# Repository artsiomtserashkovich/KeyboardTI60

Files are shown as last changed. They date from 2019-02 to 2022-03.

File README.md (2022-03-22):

TI60
===

A common 60% PCB with RGB Backlight.

## TI60 Hardware Information

    MCU: Atmega32u4
    Led Driver: IS31FL3731
    Leds: WS2812
    
    Led Pin: D2
    Led Drive Pins: D0 D1 (I2C) 

    /* Column pin configuration
    * col: 1   2   3   4   5   6   7   8   9   10   11  12  13  14  15
    * pin: F1  B0  F5  B1  F6  B2  F7  B3  C7  B7   C6  D3  B6  D5  F0
    */
     
    /* Row pin configuration
    * row: 1   2   3   4   5
    * pin: D4  D6  D7  B4  B5
    */

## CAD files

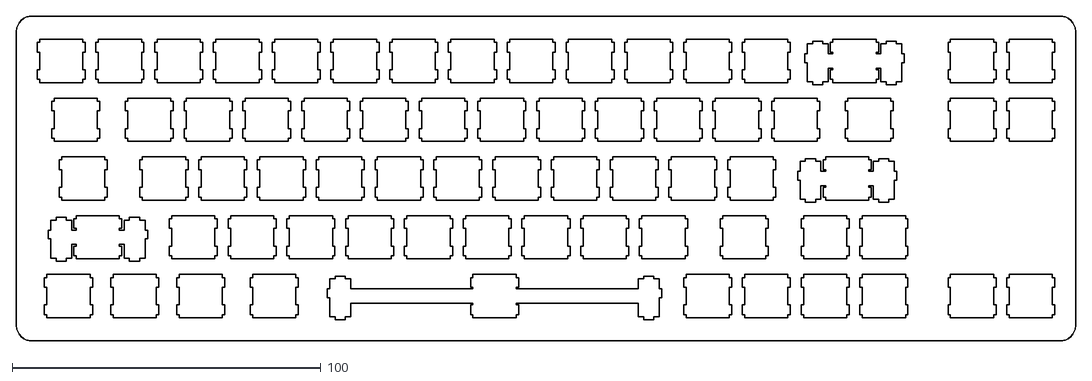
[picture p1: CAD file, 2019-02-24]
Hardware/plate/9ef09e29135e2a51376023435b0bfdb50b335f7b_switch.dxf
343.4 x 105.3

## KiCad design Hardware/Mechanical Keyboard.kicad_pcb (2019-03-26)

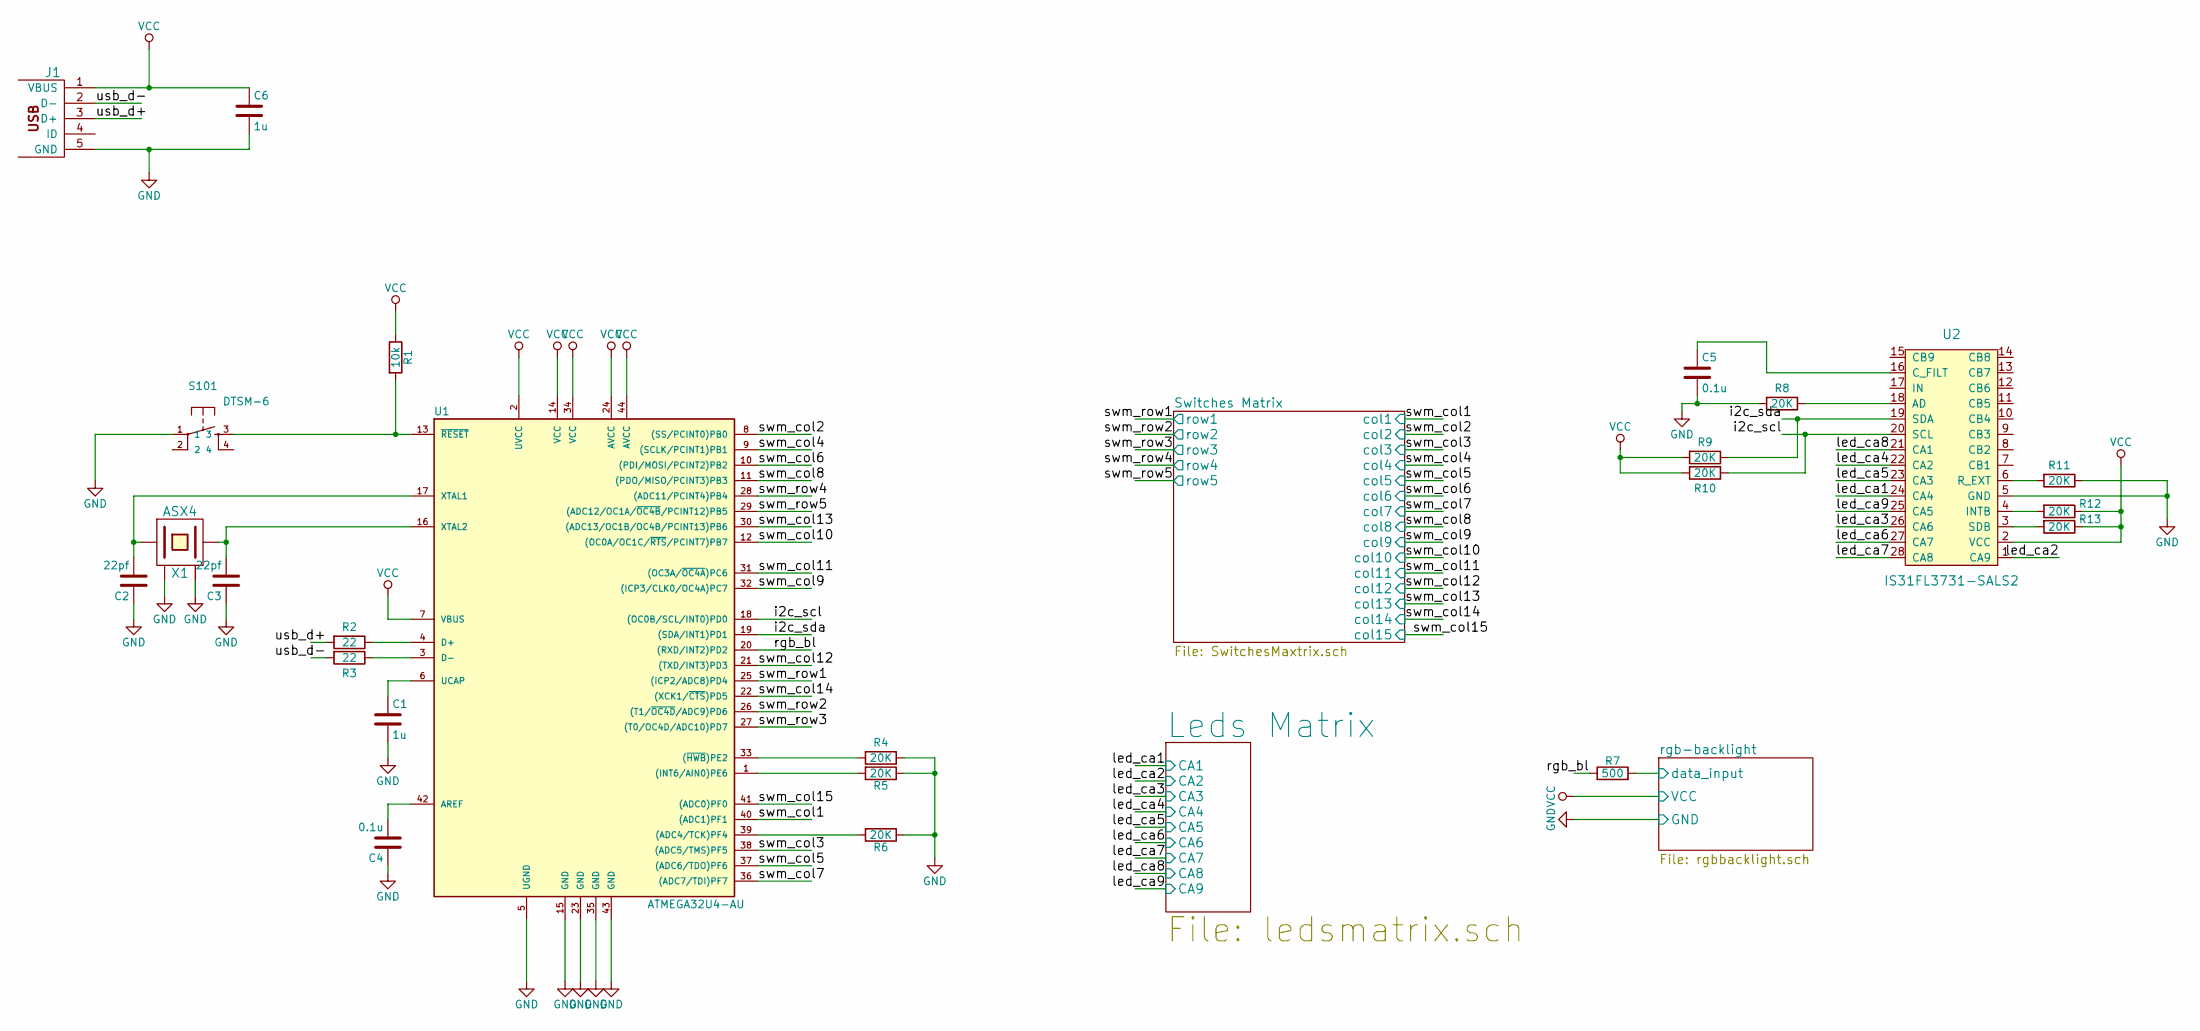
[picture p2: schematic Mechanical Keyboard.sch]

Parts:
C1, C6: 1u; C_0805_HandSoldering
C2, C3: 22pf; C_0805_HandSoldering
C4, C5: 0.1u; C_0805_HandSoldering
J1: USBMINI_B05; 67503
R1: 10k; R_0805_HandSoldering
R2, R3: 22; R_0805_HandSoldering
R4, R5, R6, R8, R9, R10, R11, R12, R13: 20K; R_0805_HandSoldering
R7: 500; R_0805_HandSoldering
S101: DTSM-6; KSEM31GLFS
U1: ATMEGA32U4-AU; TQFP-44_10x10mm_Pitch0.8mm
U2: IS31FL3731-SALS2; QFN-28-1EP_4x4mm_Pitch0.4mm
X1: ASX4; 4-SMD

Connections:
/i2c_scl: R10.1, U1.18 ((OC0B/SCL/INT0)PD0), U2.20 (SCL)
/i2c_sda: R9.1, U1.19 ((SDA/INT1)PD1), U2.19 (SDA)
/led_ca1: U2.24 (CA4); also elsewhere on the board
/led_ca2: U2.1 (CA9); also elsewhere on the board
/led_ca3: U2.26 (CA6); also elsewhere on the board
/led_ca4: U2.22 (CA2); also elsewhere on the board
/led_ca5: U2.23 (CA3); also elsewhere on the board
/led_ca6: U2.27 (CA7); also elsewhere on the board
/led_ca7: U2.28 (CA8); also elsewhere on the board
/led_ca8: U2.21 (CA1); also elsewhere on the board
/led_ca9: U2.25 (CA5); also elsewhere on the board
/rgb-backlight/data_input: R7.2; also elsewhere on the board
/rgb_bl: R7.1, U1.20 ((RXD/INT2)PD2)
/swm_col1: U1.40 ((ADC1)PF1); also elsewhere on the board
/swm_col2: U1.8 ((SS/PCINT0)PB0); also elsewhere on the board
/swm_col3: U1.38 ((ADC5/TMS)PF5); also elsewhere on the board
/swm_col4: U1.9 ((SCLK/PCINT1)PB1); also elsewhere on the board
/swm_col5: U1.37 ((ADC6/TDO)PF6); also elsewhere on the board
/swm_col6: U1.10 ((PDI/MOSI/PCINT2)PB2); also elsewhere on the board
/swm_col7: U1.36 ((ADC7/TDI)PF7); also elsewhere on the board
/swm_col8: U1.11 ((PDO/MISO/PCINT3)PB3); also elsewhere on the board
/swm_col9: U1.32 ((ICP3/CLK0/OC4A)PC7); also elsewhere on the board
/swm_col10: U1.12 ((OC0A/OC1C/~RTS~/PCINT7)PB7); also elsewhere on the board
/swm_col11: U1.31 ((OC3A/~OC4A~)PC6); also elsewhere on the board
/swm_col12: U1.21 ((TXD/INT3)PD3); also elsewhere on the board
/swm_col13: U1.30 ((ADC13/OC1B/OC4B/PCINT13)PB6); also elsewhere on the board
/swm_col14: U1.22 ((XCK1/~CTS~)PD5); also elsewhere on the board
/swm_col15: U1.41 ((ADC0)PF0); also elsewhere on the board
/swm_row1: U1.25 ((ICP2/ADC8)PD4); also elsewhere on the board
/swm_row2: U1.26 ((T1/~OC4D~/ADC9)PD6); also elsewhere on the board
/swm_row3: U1.27 ((T0/OC4D/ADC10)PD7); also elsewhere on the board
/swm_row4: U1.28 ((ADC11/PCINT4)PB4); also elsewhere on the board
/swm_row5: U1.29 ((ADC12/OC1A/~OC4B~/PCINT12)PB5); also elsewhere on the board
/usb_d+: J1.3 (D+), R2.2
/usb_d-: J1.2 (D-), R3.2
GND: C1.2, C2.1, C3.1, C4.1, C5.2, C6.2, J1.5 (GND), R4.1, R5.1, R6.1, R8.2, R11.1, S101.1, U1.5 (UGND), U1.15 (GND), U1.23 (GND), U1.35 (GND), U1.43 (GND), U2.5 (GND), X1.2 (GND), X1.4 (GND); also elsewhere on the board
unnamed: C1.1, U1.6 (UCAP)
unnamed: C2.2, U1.17 (XTAL1), X1.1
unnamed: C3.2, U1.16 (XTAL2), X1.3 (2)
unnamed: C4.2, U1.42 (AREF)
unnamed: C5.1, U2.16 (C_FILT)
unnamed: R1.2, S101.3, U1.13 (~RESET~)
unnamed: R2.1, U1.4 (D+)
unnamed: R3.1, U1.3 (D-)
unnamed: R4.2, U1.33 ((~HWB~)PE2)
unnamed: R5.2, U1.1 ((INT6/AIN0)PE6)
unnamed: R6.2, U1.39 ((ADC4/TCK)PF4)
unnamed: R8.1, U2.18 (AD)
unnamed: R11.2, U2.6 (R_EXT)
unnamed: R12.2, U2.4 (INTB)
unnamed: R13.2, U2.3 (SDB)
VCC: C6.1, J1.1 (VBUS), R1.1, R9.2, R10.2, R12.1, R13.1, U1.2 (UVCC), U1.7 (VBUS), U1.14 (VCC), U1.24 (AVCC), U1.34 (VCC), U1.44 (AVCC), U2.2 (VCC); also elsewhere on the board

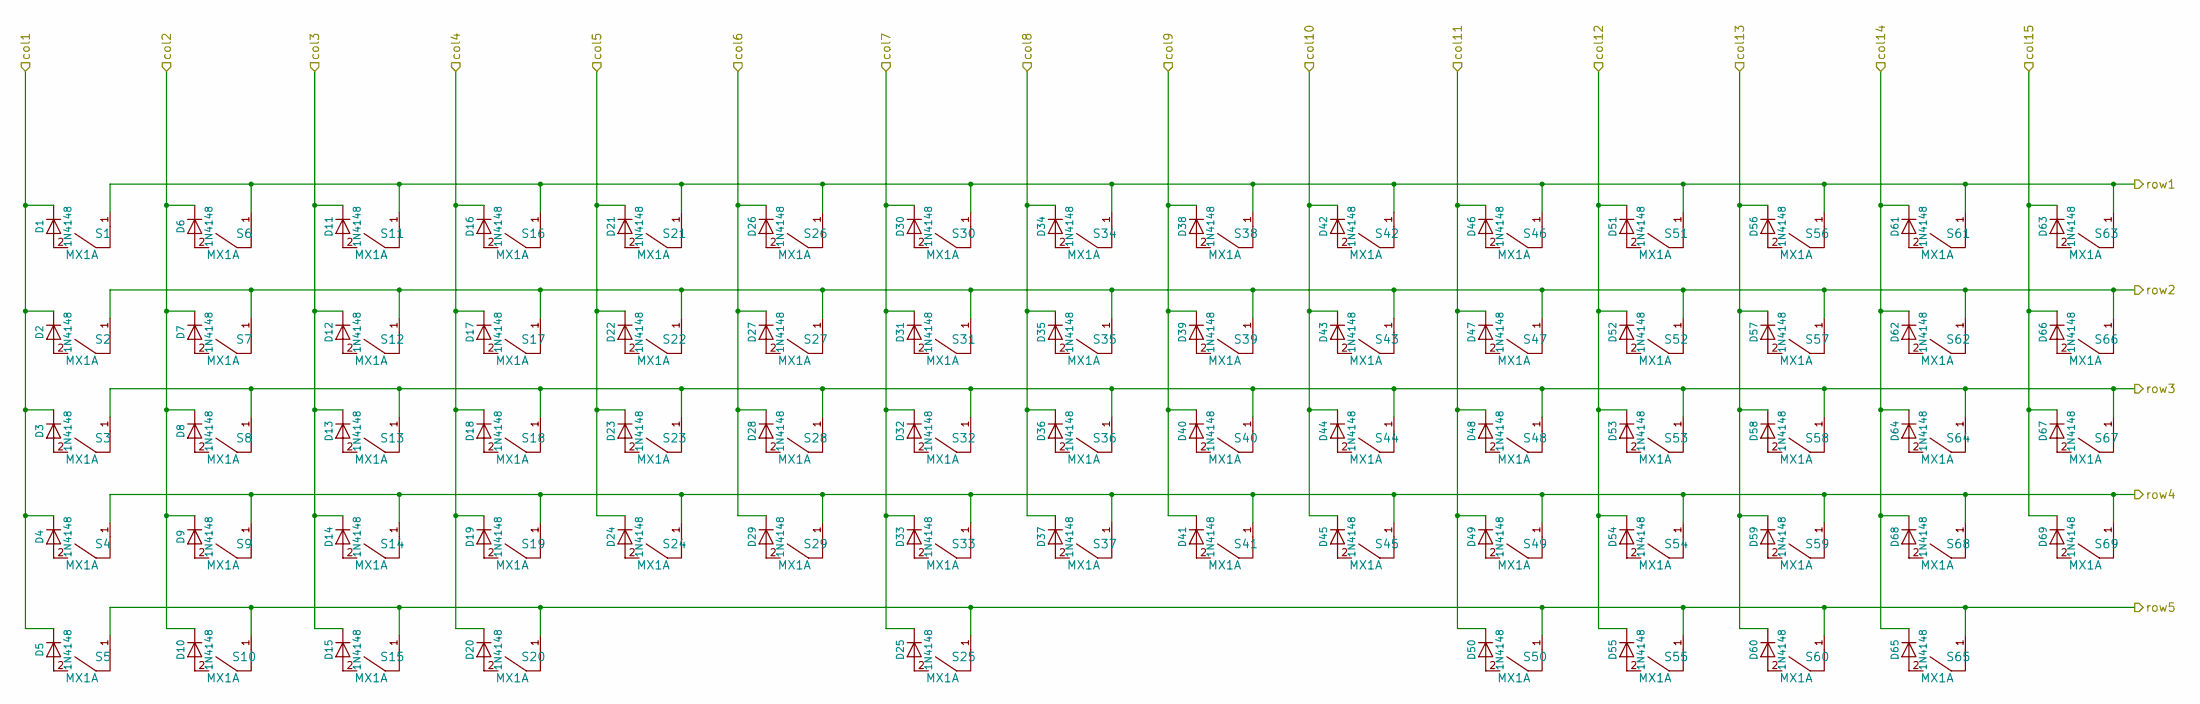
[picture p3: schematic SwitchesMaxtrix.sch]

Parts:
D1, D2, D3, D4, D5, D6, D7, D8, D9, D10, D11, D12, D13, D14, D15, D16, D17, D18, D19, D20, D21, D22, D23, D24, D25, D26, D27, D28, D29, D30, D31, D32, D33, D34, D35, D36, D37, D38, D39, D40, D41, D42, D43, D44, D45, D46, D47, D48, D49, D50, D51, D52, D53, D54, D55, D56, D57, D58, D59, D60, D61, D62, D63, D64, D65, D66, D67, D68, D69: 1N4148; D_SOD-123
S1, S2, S3, S4, S5, S6, S7, S8, S9, S10, S11, S12, S13, S14, S15, S16, S17, S18, S19, S20, S21, S22, S23, S24, S25, S26, S27, S28, S29, S30, S31, S32, S33, S34, S35, S36, S37, S38, S39, S40, S41, S42, S43, S44, S45, S46, S47, S48, S49, S50, S51, S52, S53, S54, S55, S56, S57, S58, S59, S60, S61, S62, S63, S64, S65, S66, S67, S68, S69: MX1A

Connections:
/swm_col1: D1.1 (K), D2.1 (K), D3.1 (K), D4.1 (K), D5.1 (K); also elsewhere on the board
/swm_col2: D6.1 (K), D7.1 (K), D8.1 (K), D9.1 (K), D10.1 (K); also elsewhere on the board
/swm_col3: D11.1 (K), D12.1 (K), D13.1 (K), D14.1 (K), D15.1 (K); also elsewhere on the board
/swm_col4: D16.1 (K), D17.1 (K), D18.1 (K), D19.1 (K), D20.1 (K); also elsewhere on the board
/swm_col5: D21.1 (K), D22.1 (K), D23.1 (K), D24.1 (K); also elsewhere on the board
/swm_col6: D26.1 (K), D27.1 (K), D28.1 (K), D29.1 (K); also elsewhere on the board
/swm_col7: D25.1 (K), D30.1 (K), D31.1 (K), D32.1 (K), D33.1 (K); also elsewhere on the board
/swm_col8: D34.1 (K), D35.1 (K), D36.1 (K), D37.1 (K); also elsewhere on the board
/swm_col9: D38.1 (K), D39.1 (K), D40.1 (K), D41.1 (K); also elsewhere on the board
/swm_col10: D42.1 (K), D43.1 (K), D44.1 (K), D45.1 (K); also elsewhere on the board
/swm_col11: D46.1 (K), D47.1 (K), D48.1 (K), D49.1 (K), D50.1 (K); also elsewhere on the board
/swm_col12: D51.1 (K), D52.1 (K), D53.1 (K), D54.1 (K), D55.1 (K); also elsewhere on the board
/swm_col13: D56.1 (K), D57.1 (K), D58.1 (K), D59.1 (K), D60.1 (K); also elsewhere on the board
/swm_col14: D61.1 (K), D62.1 (K), D64.1 (K), D65.1 (K), D68.1 (K); also elsewhere on the board
/swm_col15: D63.1 (K), D66.1 (K), D67.1 (K), D69.1 (K); also elsewhere on the board
/swm_row1: S1.1, S6.1, S11.1, S16.1, S21.1, S26.1, S30.1, S34.1, S38.1, S42.1, S46.1, S51.1, S56.1, S61.1, S63.1; also elsewhere on the board
/swm_row2: S2.1, S7.1, S12.1, S17.1, S22.1, S27.1, S31.1, S35.1, S39.1, S43.1, S47.1, S52.1, S57.1, S62.1, S66.1; also elsewhere on the board
/swm_row3: S3.1, S8.1, S13.1, S18.1, S23.1, S28.1, S32.1, S36.1, S40.1, S44.1, S48.1, S53.1, S58.1, S64.1, S67.1; also elsewhere on the board
/swm_row4: S4.1, S9.1, S14.1, S19.1, S24.1, S29.1, S33.1, S37.1, S41.1, S45.1, S49.1, S54.1, S59.1, S68.1, S69.1; also elsewhere on the board
/swm_row5: S5.1, S10.1, S15.1, S20.1, S25.1, S50.1, S55.1, S60.1, S65.1; also elsewhere on the board
unnamed: D1.2 (A), S1.2
unnamed: D2.2 (A), S2.2
unnamed: D3.2 (A), S3.2
unnamed: D4.2 (A), S4.2
unnamed: D5.2 (A), S5.2
unnamed: D6.2 (A), S6.2
unnamed: D7.2 (A), S7.2
unnamed: D8.2 (A), S8.2
unnamed: D9.2 (A), S9.2
unnamed: D10.2 (A), S10.2
unnamed: D11.2 (A), S11.2
unnamed: D12.2 (A), S12.2
unnamed: D13.2 (A), S13.2
unnamed: D14.2 (A), S14.2
unnamed: D15.2 (A), S15.2
unnamed: D16.2 (A), S16.2
unnamed: D17.2 (A), S17.2
unnamed: D18.2 (A), S18.2
unnamed: D19.2 (A), S19.2
unnamed: D20.2 (A), S20.2
unnamed: D21.2 (A), S21.2
unnamed: D22.2 (A), S22.2
unnamed: D23.2 (A), S23.2
unnamed: D24.2 (A), S24.2
unnamed: D25.2 (A), S25.2
unnamed: D26.2 (A), S26.2
unnamed: D27.2 (A), S27.2
unnamed: D28.2 (A), S28.2
unnamed: D29.2 (A), S29.2
unnamed: D30.2 (A), S30.2
unnamed: D31.2 (A), S31.2
unnamed: D32.2 (A), S32.2
unnamed: D33.2 (A), S33.2
unnamed: D34.2 (A), S34.2
unnamed: D35.2 (A), S35.2
unnamed: D36.2 (A), S36.2
unnamed: D37.2 (A), S37.2
unnamed: D38.2 (A), S38.2
unnamed: D39.2 (A), S39.2
unnamed: D40.2 (A), S40.2
unnamed: D41.2 (A), S41.2
unnamed: D42.2 (A), S42.2
unnamed: D43.2 (A), S43.2
unnamed: D44.2 (A), S44.2
unnamed: D45.2 (A), S45.2
unnamed: D46.2 (A), S46.2
unnamed: D47.2 (A), S47.2
unnamed: D48.2 (A), S48.2
unnamed: D49.2 (A), S49.2
unnamed: D50.2 (A), S50.2
unnamed: D51.2 (A), S51.2
unnamed: D52.2 (A), S52.2
unnamed: D53.2 (A), S53.2
unnamed: D54.2 (A), S54.2
unnamed: D55.2 (A), S55.2
unnamed: D56.2 (A), S56.2
unnamed: D57.2 (A), S57.2
unnamed: D58.2 (A), S58.2
unnamed: D59.2 (A), S59.2
unnamed: D60.2 (A), S60.2
unnamed: D61.2 (A), S61.2
unnamed: D62.2 (A), S62.2
unnamed: D63.2 (A), S63.2
unnamed: D64.2 (A), S64.2
unnamed: D65.2 (A), S65.2
unnamed: D66.2 (A), S66.2
unnamed: D67.2 (A), S67.2
unnamed: D68.2 (A), S68.2
unnamed: D69.2 (A), S69.2

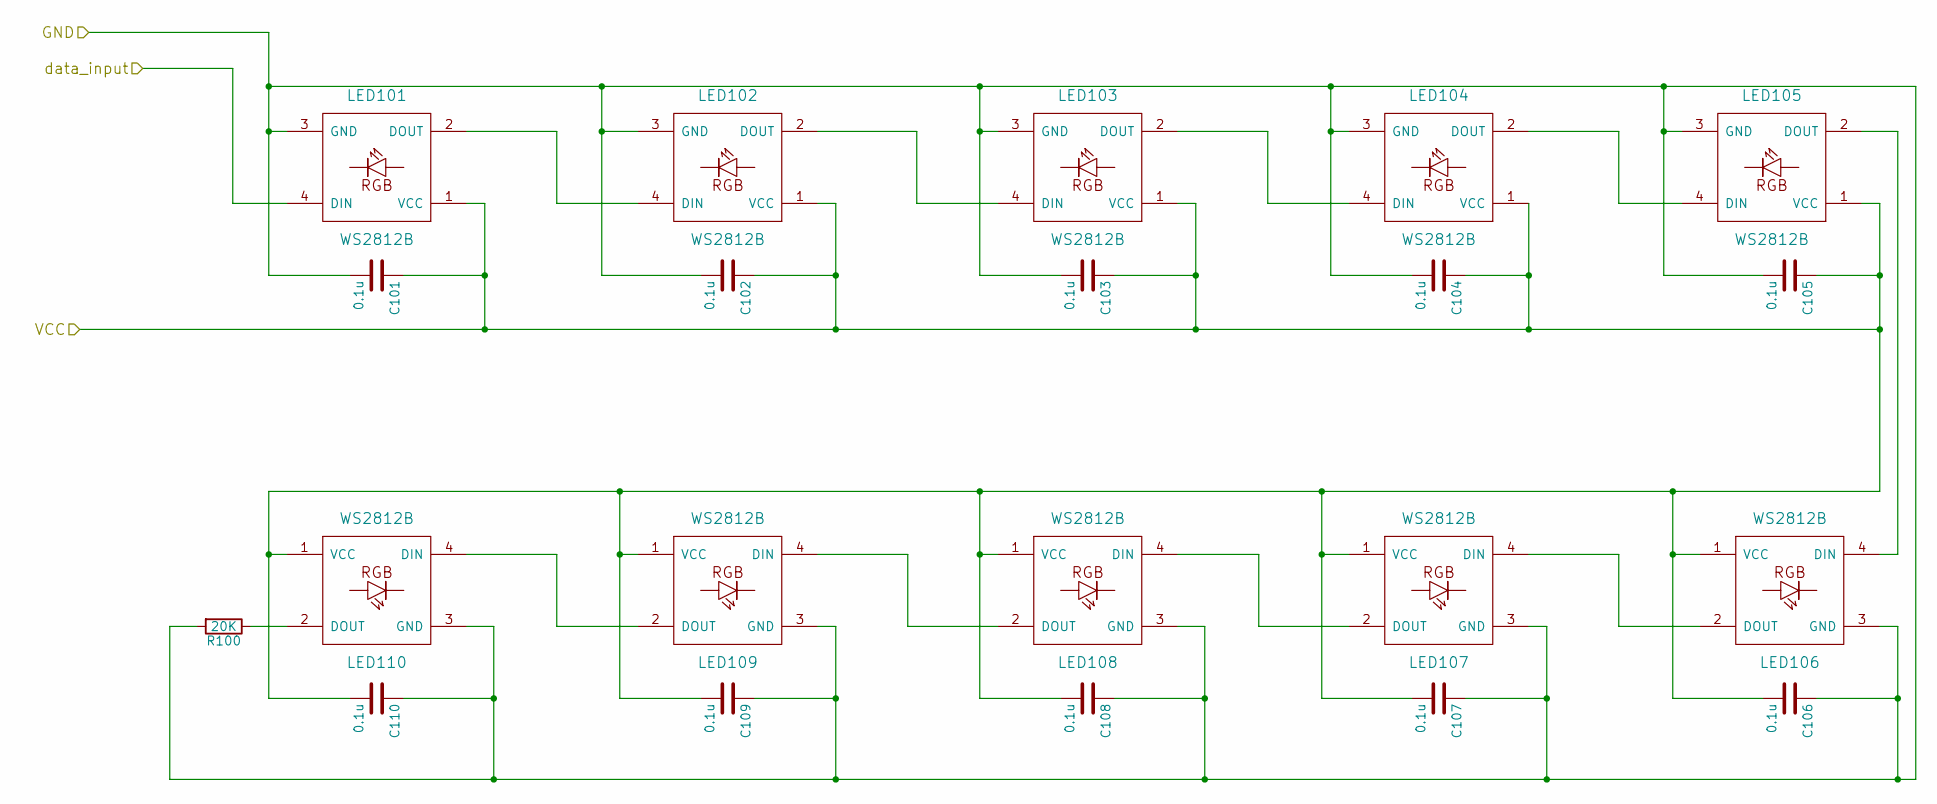
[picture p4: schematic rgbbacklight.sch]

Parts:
C101, C102, C103, C104, C105, C106, C107, C108, C109, C110: 0.1u; C_0805_HandSoldering
LED101, LED102, LED103, LED104, LED105, LED106, LED107, LED108, LED109, LED110: WS2812B
R100: 20K; R_0805_HandSoldering

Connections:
/rgb-backlight/data_input: LED101.4 (DIN); also elsewhere on the board
GND: C101.2, C102.2, C103.2, C104.2, C105.2, C106.1, C107.1, C108.1, C109.1, C110.1, LED101.3 (GND), LED102.3 (GND), LED103.3 (GND), LED104.3 (GND), LED105.3 (GND), LED106.3 (GND), LED107.3 (GND), LED108.3 (GND), LED109.3 (GND), LED110.3 (GND), R100.2; also elsewhere on the board
unnamed: LED101.2 (DOUT), LED102.4 (DIN)
unnamed: LED102.2 (DOUT), LED103.4 (DIN)
unnamed: LED103.2 (DOUT), LED104.4 (DIN)
unnamed: LED104.2 (DOUT), LED105.4 (DIN)
unnamed: LED105.2 (DOUT), LED106.4 (DIN)
unnamed: LED106.2 (DOUT), LED107.4 (DIN)
unnamed: LED107.2 (DOUT), LED108.4 (DIN)
unnamed: LED108.2 (DOUT), LED109.4 (DIN)
unnamed: LED109.2 (DOUT), LED110.4 (DIN)
unnamed: LED110.2 (DOUT), R100.1
VCC: C101.1, C102.1, C103.1, C104.1, C105.1, C106.2, C107.2, C108.2, C109.2, C110.2, LED101.1 (VCC), LED102.1 (VCC), LED103.1 (VCC), LED104.1 (VCC), LED105.1 (VCC), LED106.1 (VCC), LED107.1 (VCC), LED108.1 (VCC), LED109.1 (VCC), LED110.1 (VCC); also elsewhere on the board

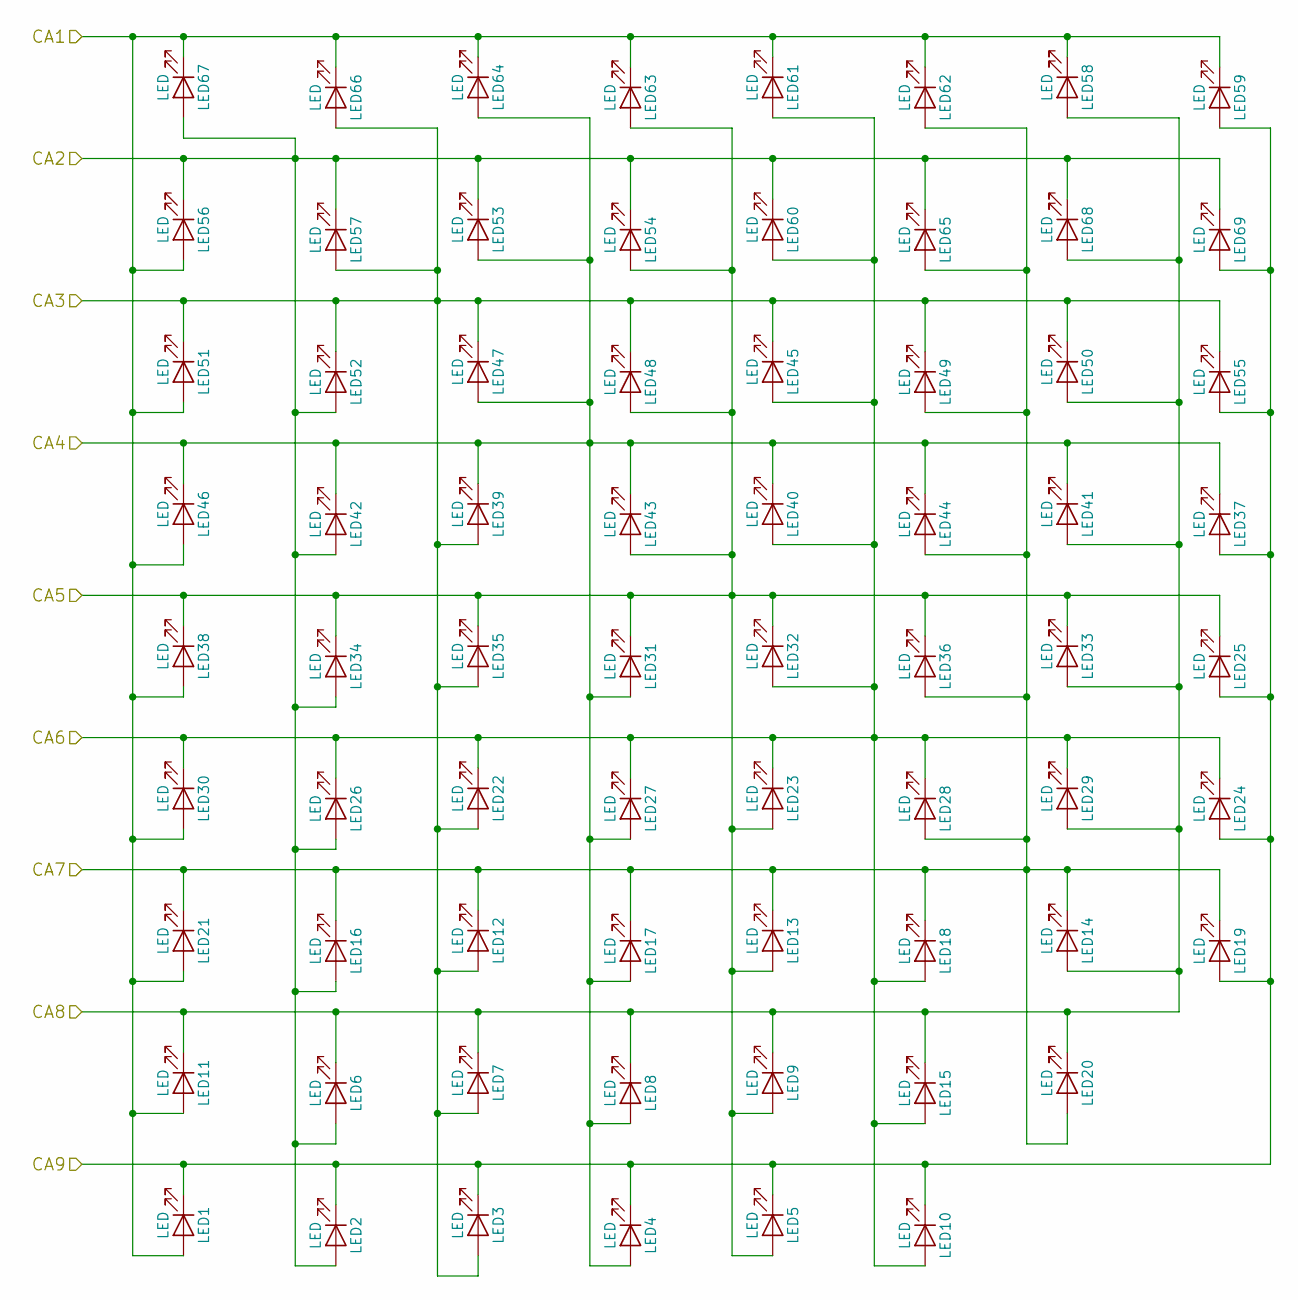
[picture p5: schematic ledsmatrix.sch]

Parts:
LED1, LED2, LED3, LED4, LED5, LED6, LED7, LED8, LED9, LED10, LED11, LED12, LED13, LED14, LED15, LED16, LED17, LED18, LED19, LED20, LED21, LED22, LED23, LED24, LED25, LED26, LED27, LED28, LED29, LED30, LED31, LED32, LED33, LED34, LED35, LED36, LED37, LED38, LED39, LED40, LED41, LED42, LED43, LED44, LED45, LED46, LED47, LED48, LED49, LED50, LED51, LED52, LED53, LED54, LED55, LED56, LED57, LED58, LED59, LED60, LED61, LED62, LED63, LED64, LED65, LED66, LED67, LED68, LED69: LED; MX1A-led

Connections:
/led_ca1: LED1.2 (A), LED11.2 (A), LED21.2 (A), LED30.2 (A), LED38.2 (A), LED46.2 (A), LED51.2 (A), LED56.2 (A), LED58.1 (K), LED59.1 (K), LED61.1 (K), LED62.1 (K), LED63.1 (K), LED64.1 (K), LED66.1 (K), LED67.1 (K); also elsewhere on the board
/led_ca2: LED2.2 (A), LED6.2 (A), LED16.2 (A), LED26.2 (A), LED34.2 (A), LED42.2 (A), LED52.2 (A), LED53.1 (K), LED54.1 (K), LED56.1 (K), LED57.1 (K), LED60.1 (K), LED65.1 (K), LED67.2 (A), LED68.1 (K), LED69.1 (K); also elsewhere on the board
/led_ca3: LED3.2 (A), LED7.2 (A), LED12.2 (A), LED22.2 (A), LED35.2 (A), LED39.2 (A), LED45.1 (K), LED47.1 (K), LED48.1 (K), LED49.1 (K), LED50.1 (K), LED51.1 (K), LED52.1 (K), LED55.1 (K), LED57.2 (A), LED66.2 (A); also elsewhere on the board
/led_ca4: LED4.2 (A), LED8.2 (A), LED17.2 (A), LED27.2 (A), LED31.2 (A), LED37.1 (K), LED39.1 (K), LED40.1 (K), LED41.1 (K), LED42.1 (K), LED43.1 (K), LED44.1 (K), LED46.1 (K), LED47.2 (A), LED53.2 (A), LED64.2 (A); also elsewhere on the board
/led_ca5: LED5.2 (A), LED9.2 (A), LED13.2 (A), LED23.2 (A), LED25.1 (K), LED31.1 (K), LED32.1 (K), LED33.1 (K), LED34.1 (K), LED35.1 (K), LED36.1 (K), LED38.1 (K), LED43.2 (A), LED48.2 (A), LED54.2 (A), LED63.2 (A); also elsewhere on the board
/led_ca6: LED10.2 (A), LED15.2 (A), LED18.2 (A), LED22.1 (K), LED23.1 (K), LED24.1 (K), LED26.1 (K), LED27.1 (K), LED28.1 (K), LED29.1 (K), LED30.1 (K), LED32.2 (A), LED40.2 (A), LED45.2 (A), LED60.2 (A), LED61.2 (A); also elsewhere on the board
/led_ca7: LED12.1 (K), LED13.1 (K), LED14.1 (K), LED16.1 (K), LED17.1 (K), LED18.1 (K), LED19.1 (K), LED20.2 (A), LED21.1 (K), LED28.2 (A), LED36.2 (A), LED44.2 (A), LED49.2 (A), LED62.2 (A), LED65.2 (A); also elsewhere on the board
/led_ca8: LED6.1 (K), LED7.1 (K), LED8.1 (K), LED9.1 (K), LED11.1 (K), LED14.2 (A), LED15.1 (K), LED20.1 (K), LED29.2 (A), LED33.2 (A), LED41.2 (A), LED50.2 (A), LED58.2 (A), LED68.2 (A); also elsewhere on the board
/led_ca9: LED1.1 (K), LED2.1 (K), LED3.1 (K), LED4.1 (K), LED5.1 (K), LED10.1 (K), LED19.2 (A), LED24.2 (A), LED25.2 (A), LED37.2 (A), LED55.2 (A), LED59.2 (A), LED69.2 (A); also elsewhere on the board

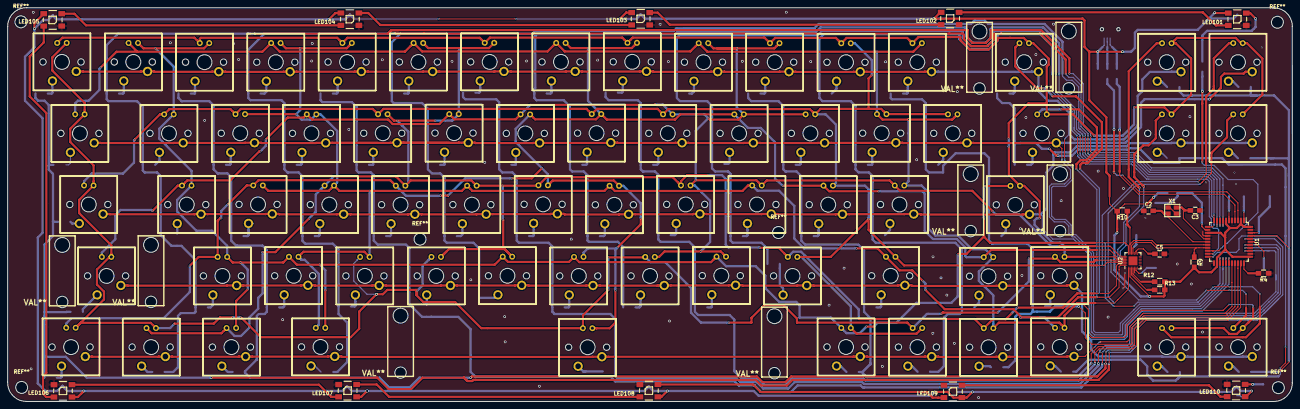
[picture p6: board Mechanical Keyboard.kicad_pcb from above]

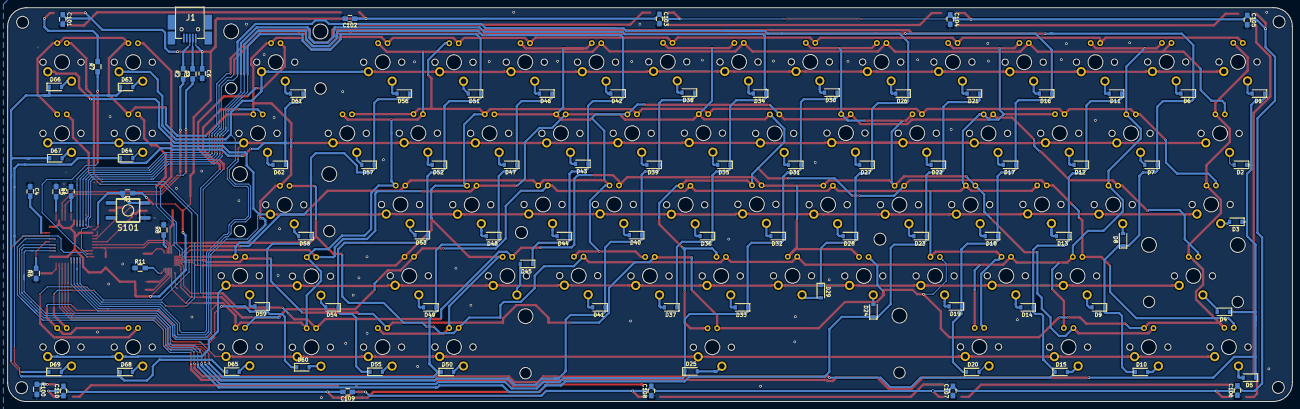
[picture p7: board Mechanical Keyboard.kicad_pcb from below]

Board: 2 copper layers, 343.4 x 105.3 mm, 260 parts (93 on the bottom side), 131 nets.

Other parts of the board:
MXST: VAL**; MXST
MXST#2, MXST#3, MXST#4, MXST#5, MXST#6, MXST#7, MXST#8: VAL**; MXST

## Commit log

2019-03-03 Move diodes and resistors
    [Mechanical Keyboard-2019-03-03-10-05-13.sch, Mechanical Keyboard.kicad_pcb, Mechanical Keyboard.sch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]
2019-03-03 Add BOM list and add cut area
    [Mechanical Keyboard.kicad_pcb, _saved_Mechanical Keyboard.sch]
2019-03-03 Implement wiring
    [Mechanical Keyboard.kicad_pcb]
2019-03-04 wiring keys
    [Mechanical Keyboard.kicad_pcb, _saved_Mechanical Keyboard.sch]
2019-03-07 refactor wiring
    [Mechanical Keyboard.kicad_pcb, _saved_Mechanical Keyboard.sch]
2019-03-25 Keyboard tracking was finished. Only GND circuit is left
    [Mechanical Keyboard.kicad_pcb, Mechanical Keyboard.sch]
2019-03-25 Small refactoring
    [Mechanical Keyboard.kicad_pcb]
2019-03-25 Bugfix for swm_col11 connection to atmega
    [Mechanical Keyboard.kicad_pcb]
2019-03-25 Temporary solution with GND filling
    [Mechanical Keyboard.kicad_pcb, _saved_Mechanical Keyboard.sch]
2019-03-25 GND curcuit fill was finished
    [Mechanical Keyboard.kicad_pcb]
2019-03-25 Bugfix for swm_col9
    [Mechanical Keyboard.kicad_pcb, Mechanical Keyboard.sch, SwitchesMaxtrix.sch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]
2019-03-25 add driling holes
    [Mechanical Keyboard-B.Adhes.gbr, Mechanical Keyboard-B.CrtYd.gbr, Mechanical Keyboard-B.Cu.gbr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]
2019-03-26 Atmega 5 GND pin refactoring
    [Mechanical Keyboard.kicad_pcb]
2019-05-08 clean up project
    [Mechanical Keyboard-2019-03-03-10-05-13.sch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]
